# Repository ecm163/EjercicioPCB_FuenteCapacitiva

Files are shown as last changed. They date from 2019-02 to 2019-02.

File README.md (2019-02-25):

# EjercicioPCB_FuenteCapacitiva

Ejercicio Simulación y Diseño del PCB de una Fuente Capacitiva (hecho por ecm163).

La fuente capacitiva es un circuito que transforma una corriente alterna, por ejemplo la de 220  voltios rms de la red, 
en una continua de menor voltaje, en este ejercicio unos 5 voltios aproximadamente. 

En éste ejercicio se hacen dos cosas:

1- Se diseña y simula el circuito en Orcad y Pspice (versión 17.2).

2- Se diseña su correspondiente PCB con Altium Designer.

Una descripción sintética sel ejercicio se en el PDF que se adjunta con el nombre: 

"Ejercicio Simulación y Diseño del PCB de una Fuente Capacitiva".

Dentro de la carpeta: "Fuente capacitiva" tenemos dos carpetas más.

- "EjercicioOrcadPCB". En ésta carpeta se encuentran los archivos correspondientes al proyecto en Orcad (versión 17.2),
  que consta de su esquemático para ser simulado. Si dispone del Orcad puede navegar en ésta carpeta y abrir el proyecto.
  
- "EjercicioAltium". En ésta carpeta se encuentran los archivos correspondientes al proyecto en Altium Designer,
  que consta de su esquemático y el layout o PCB final del diseño.
  Si dispone del Altium Designer puede navegar en ésta carpeta y abrir el proyecto.

Un saludo.

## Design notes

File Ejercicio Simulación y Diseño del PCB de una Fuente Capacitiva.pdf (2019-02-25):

## Ejercicio Simulación y Diseño del PCB de una Fuente

Capacitiva.

## Introducción:

La fuente capacitiva es un circuito que transforma una corriente alterna, por ejemplo la de 220 voltios rms de la red, en una continua de menor voltaje, en este ejercicio unos 5 voltios aproximadamente.

Hay otra forma de realizar esta operación con un transformador. De esta forma se usa el efecto capacitivo de un condensador electrolítico previamente rectificado la señal en alterna por un puente de diodos, además de un diodo zener para fijar una tensión de salida entre otros componentes. Como todo está forma de realizar el propósito tiene sus ventajas e inconvenientes.

La parte de simulación está hecha con la última versión de Orcad (la 17.2) y su correspondiente Pspice. Yo he manejado versiones más antiguas de Orcad con las que no me resultaba difícil sacar la PCB, y dónde la herramienta era el layout o layout plus, en esta versión la herramienta es el PCB editor, que en mi ordenador va muy lento.

Como no controlo tan bien el PCB editor y va excesivamente lento decidí finalmente desarrollar el PCB con Altium, incluso aunque mi versión de Altium Designer va “a trompicones”, es una herramienta con la que tengo más soltura y se trataba de hacer algo de la mejor forma en poco tiempo.

El desarrollo y diseño del ejercicio es mejorable, pero creo que puede ser suficiente para demostrar que tengo cierto manejo en simulación y diseño de PCBs.

Dado que esto no es un tutorial, en la sucesivo trataré de ser lo más sintético posible usando más capturas de pantalla que mucha literatura.
Simulación con Orcad-Pspice.

En primer lugar diseñé el esquemático en la herramienta Capture del Orcad para comprobar que el circuito funciona:

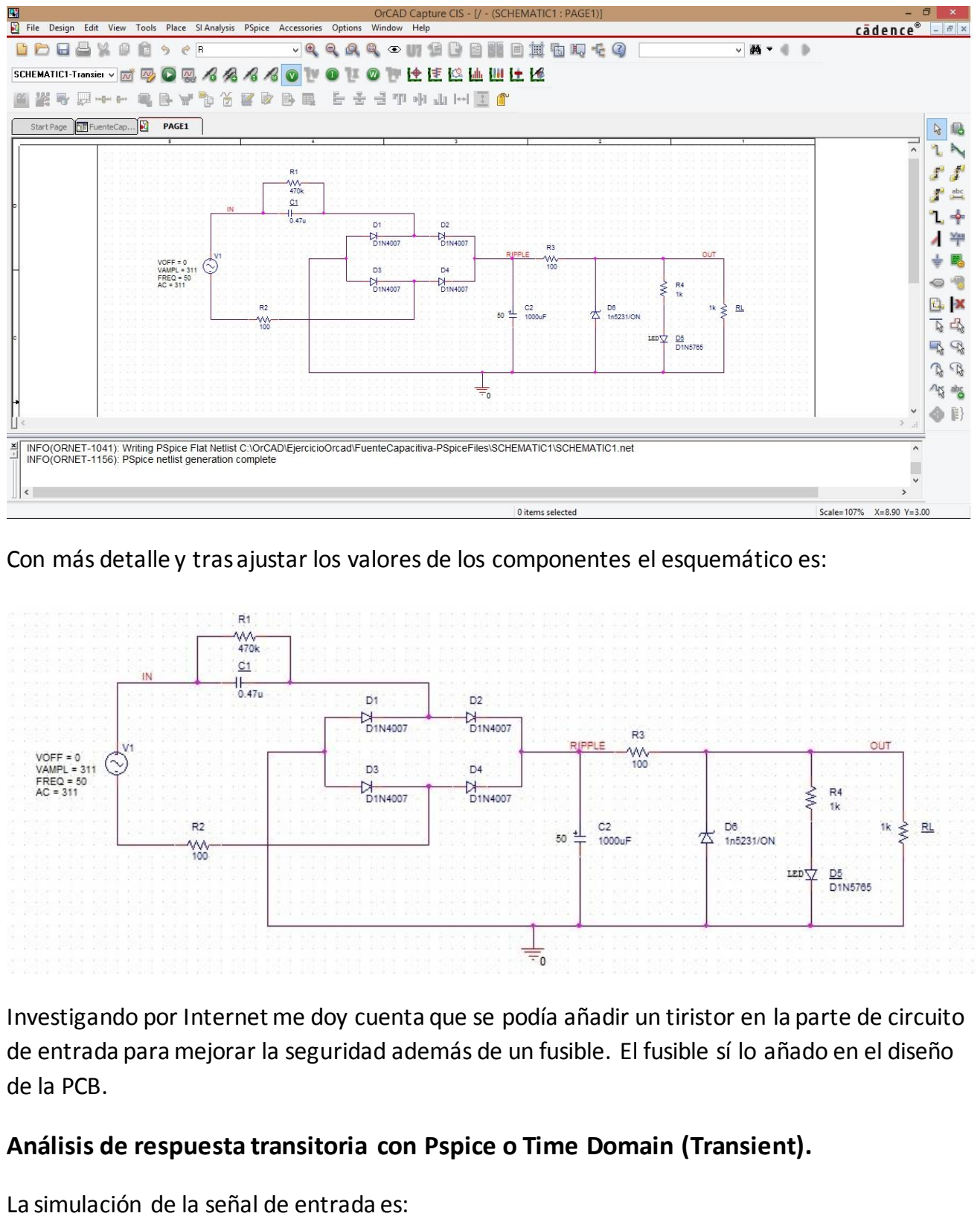
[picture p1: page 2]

Con más detalle y trasajustar los valores de los componentes el esquemático es:

Investigando por Internet me doy cuenta que se podía añadir un tiristor en la parte de circuito de entrada para mejorar la seguridad además de un fusible. El fusible sí lo añado en el diseño de la PCB.

Análisis de respuesta transitoria con Pspice o Time Domain (Transient).

La simulación de la señal de entrada es:

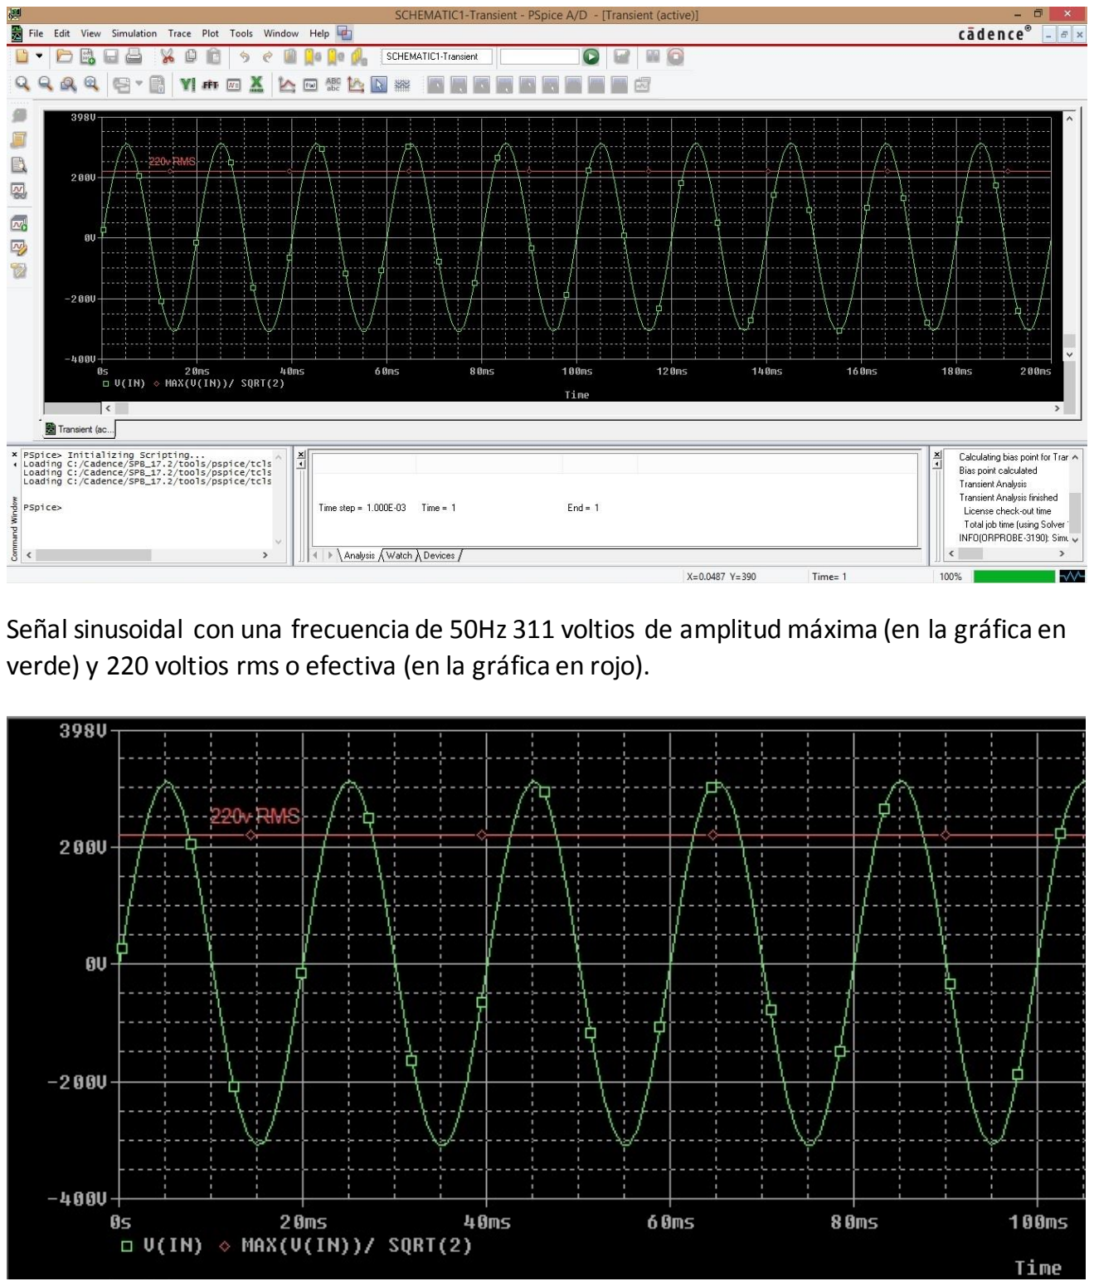
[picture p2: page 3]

Señal sinusoidal con una frecuencia de 50Hz 311 voltios de amplitud máxima (en la gráfica en verde) y 220 voltios rms o efectiva (en la gráfica en rojo).

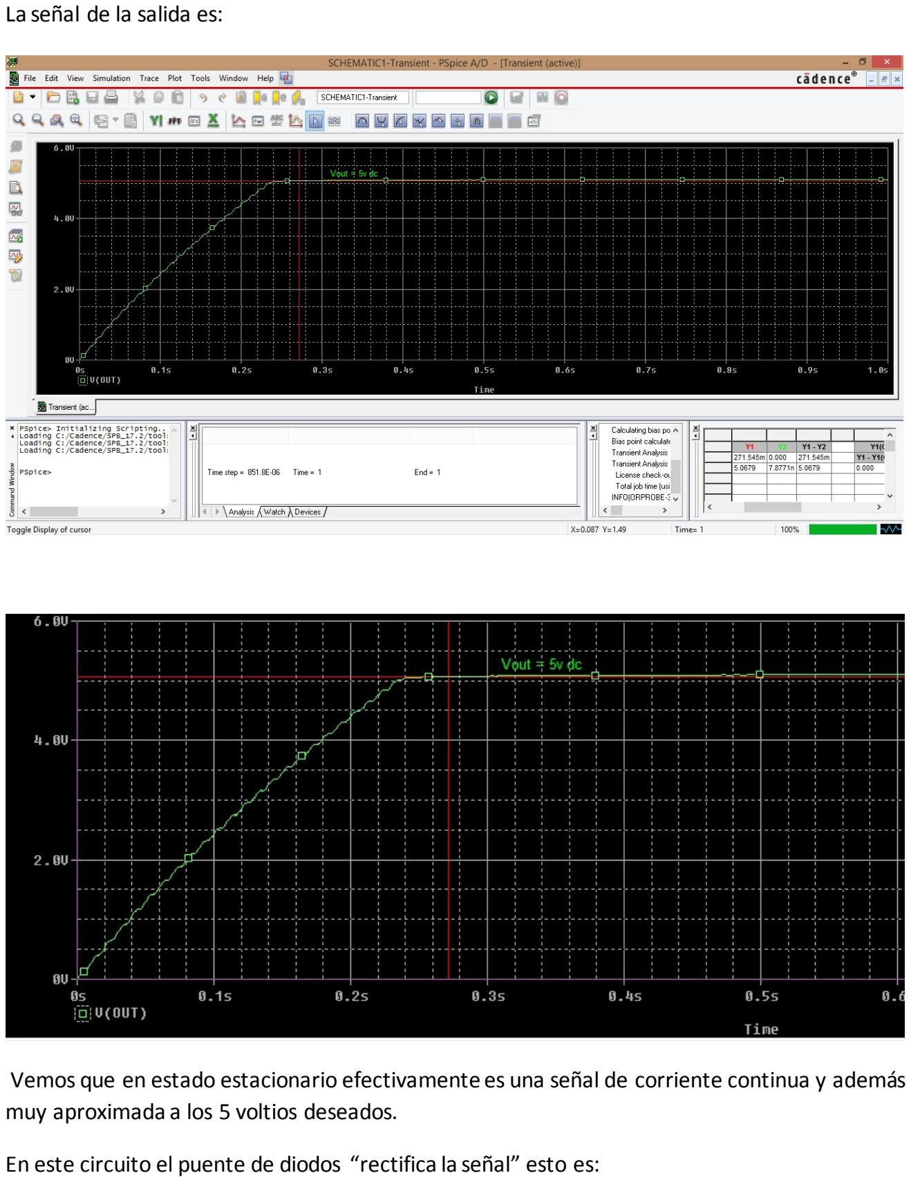
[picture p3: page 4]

La señal de la salida es:

Vemos que en estado estacionario efectivamente es una señal de corriente continua y además muy aproximada a los 5 voltios deseados.

En este circuito el puente de diodos “rectifica la señal” esto es:

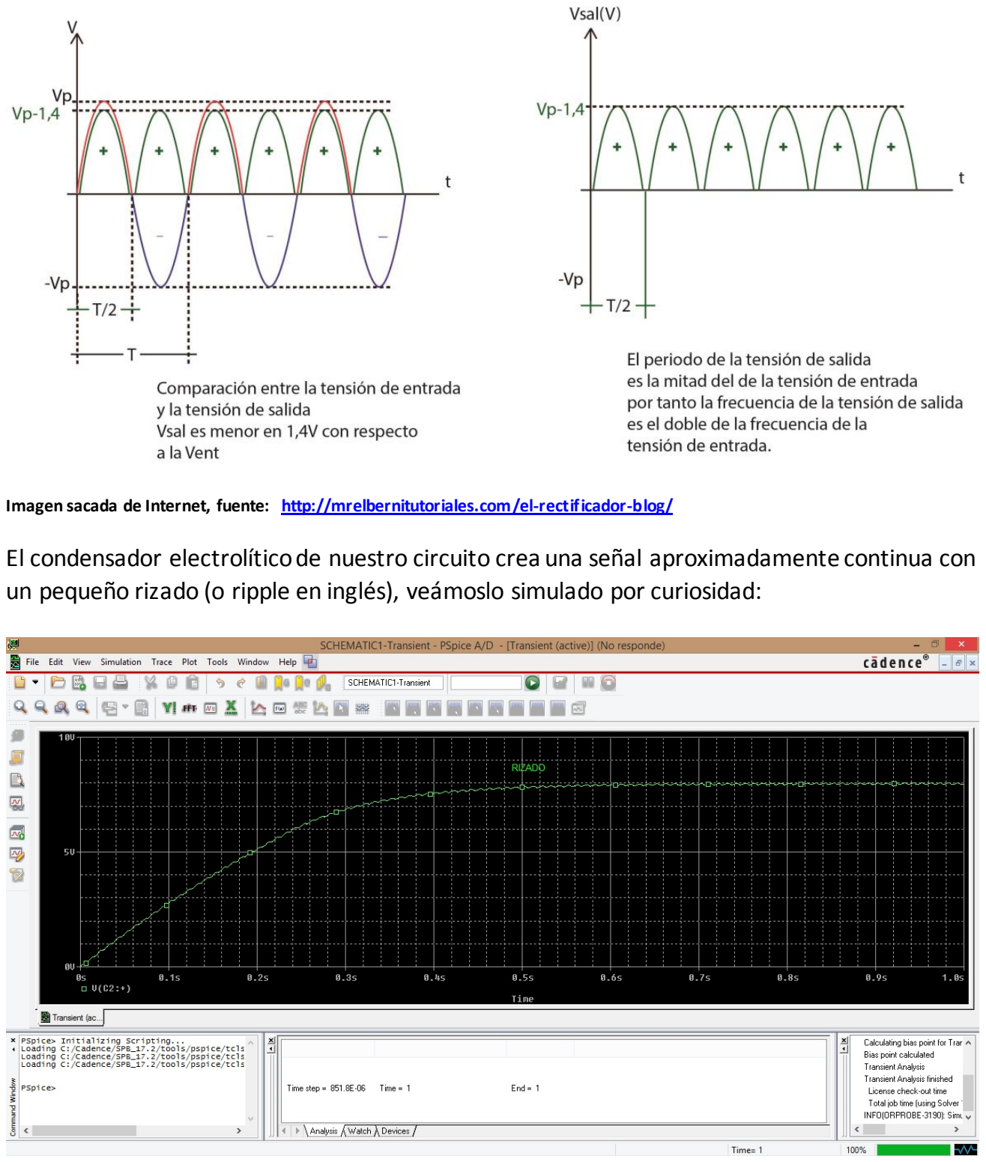
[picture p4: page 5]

Imagen sacada de Internet, fuente: http://mrelbernitutoriales.com/el-rectificador-blog/

El condensador electrolítico de nuestro circuito crea una señal aproximadamente continua con un pequeño rizado (o ripple en inglés), veámoslo simulado por curiosidad:

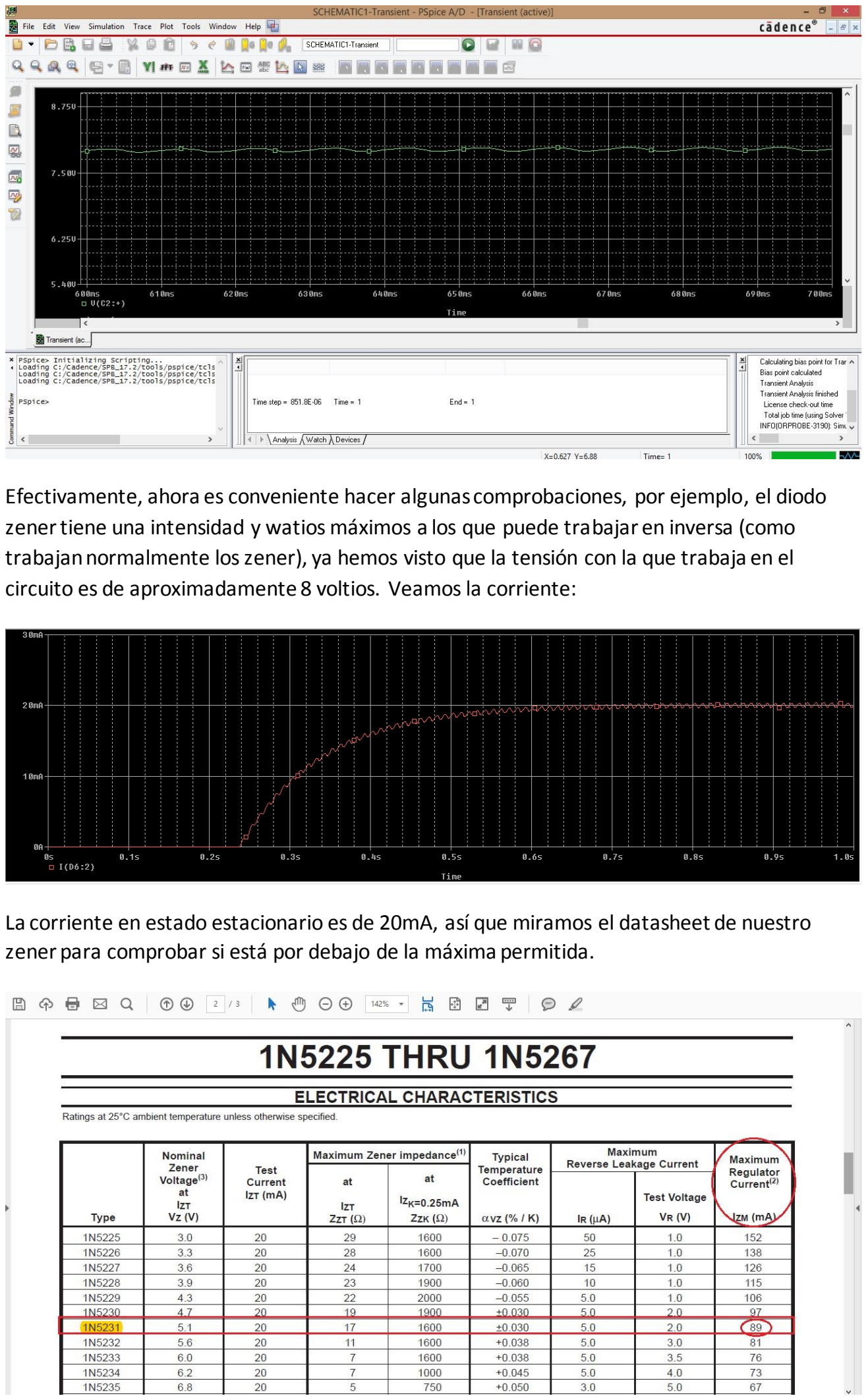
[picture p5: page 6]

Efectivamente, ahora es conveniente hacer algunas comprobaciones, por ejemplo, el diodo zener tiene una intensidad y watios máximos a los que puede trabajar en inversa (como trabajan normalmente los zener), ya hemos visto que la tensión con la que trabaja en el circuito es de aproximadamente 8 voltios. Veamosla corriente:

La corriente en estado estacionario es de 20mA, así que miramos el datasheet de nuestro zener para comprobar si está por debajo de la máxima permitida.

Tenemos 20mA, por debajo de los 89mA máximos permitidos. Vamos bien.

Además los watios que soporta el zenersería de 0,5 o 1 (ya no recuerdo), pongamos el peor caso, 0,5w. Como sabemos la corriente que pasa por él y la caída de tensión (20mA y 8V respectivamente)sería aproximadamente de:

W = I x V = 0,16w

Bastante por debajo de 0,5w.

No está mal hacer comprobaciones de este tipo. Además como la tensión suministrada no es fija siempre a 220v (hay picos de tensión que sobrepasan los 311v de amplitud) no está de más hacer un análisis AC sweep entre las amplitudes de la señal correspondientes a por ejemplo 200 y 240 voltios rms o eficaces (esto es, entre 140v y 170v de amplitud máxima aproximadamente). Pero es mejor no alargar mucho más esto.
Diseño del PCB con el Altium Designer.

El esquemático en el Altium -en el que añado un fusible, sustituyo la fuente ac por un terminal de empalme de cables para PCBs a la entrada y un conector de salida- sería:

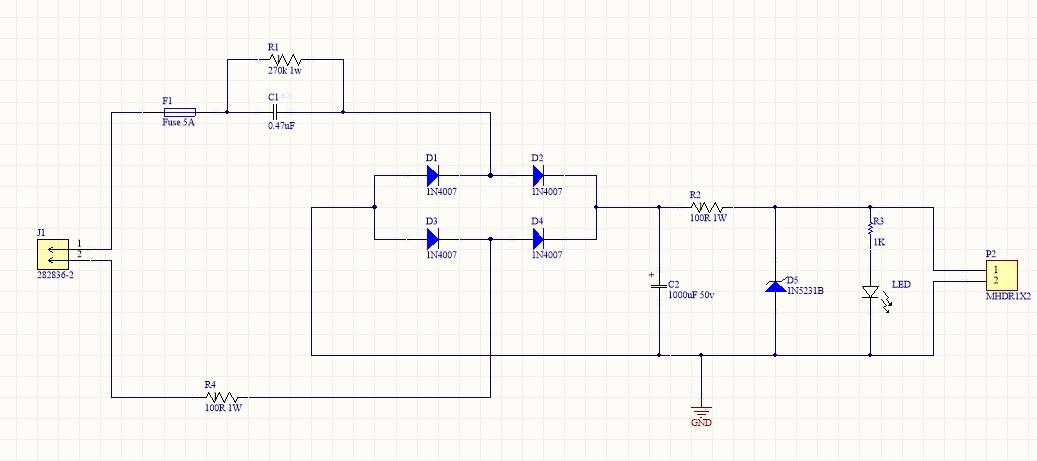
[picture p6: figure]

En el proceso de diseño del esquemático me aseguré de que cada componente tuviera su footprint real, el del componente que seleccioné (en páginas como digikey, RS-online, Farnell …etc).

¿Cómo hice esto?, bueno, en algún caso tiré de datasheet e hice el diseño correspondiente con el Altium (clic botón derecho en el proyecto, desplegable, add new to Project/PCB Library).

Otros estaban en las librerías que he recopilado con el tiempo de Altium, y por último algunos suministradores de componentes -como digkey- te dan la posibilidad de descargarte y trasla ejecución de scripts obtener el esquemático del componente con su footprint (con una herramienta llamada ultra-librarian).

También está la opción para descargar modelos de una página llamada SanapEda, pero mientras que en el Orcad me iba muy bien, en mi versión de Altium no …

Componente: | Unidades | N o Serie Fabricante | Breve descripción
J1 | 1 | 282836-2 | Bloque de terminales fijos
F1 | 1 | 0876005.MRET1P | Fusible 250v 5A
C1 | 1 | MKT1822447405 | Condensador poliéster de 0,47uF 400v
C2 | 1 | UVY1H102MHD | Condensador electrolítico 1000uF y 50v
R1 | 1 | PR01000104703JR500 | Resistencia 270k y 1W
R2,R4 | 2 | FMP100JR-52-100R | Resistencias 100 y 1W
R3 | 1 | CF14JT1K00 | Resistencia 1k y 0,25W (el tipo habitual)
D1,D2,D3 y D4 | 1 | 1N4007 | Diodo de propósito general de 1ª 1Kv
D5 | 1 | 1N5231BTR | Diodo zener 5,1v y 0,5w
LED | 1 | HLMP-1301 | LED orificio pasante (los más habituales)
P2 | 1 | HDR1X2-M254-72 | Conectores PCB macho

Si completáramosla anterior tabla con más información como el vendedor, marca del fabricante … y añadiría el precio, tendríamos lo que se llama la “bill of material” o conocido con el acrónimo de BOM, dejo la anterior tabla para atestiguar que he trabajado la cuestión de la elección de componentes. No ha sido al azar.

Una vez hecho el esquemático y la selección de componentes y sus footprints diseñé el PCB:

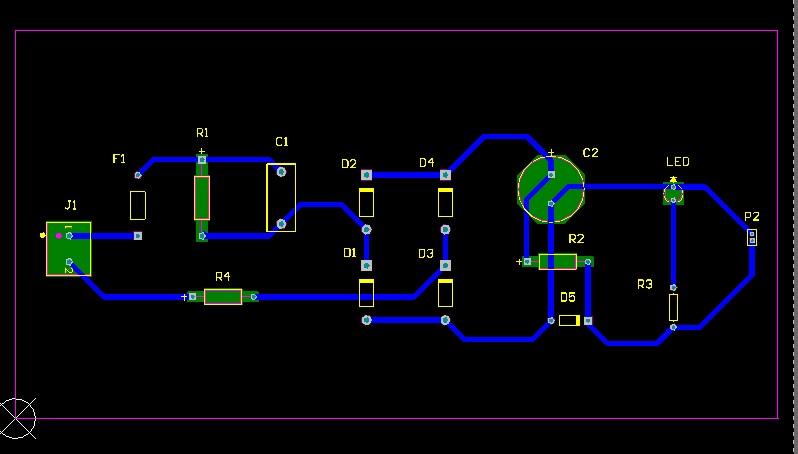
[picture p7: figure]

El ruteado lo hice manual, las pistas son de 40 mils (o milipulgadas) que corresponde aproximadamente a un milímetro en sistema métrico, en este caso creo que es un ancho de pista óptimo. El borde de la placa (en morado) aquí lo he puesto como me ha parecido, pero en caso de que el diseño fuera para fabricación lo óptimo es ajustar sus dimensiones a los estándares del fabricante.

A continuación le incorporamos un plano a masa, más concretamente a tierra, mejora la respuesta al ruido y evita corrientes parásitas.

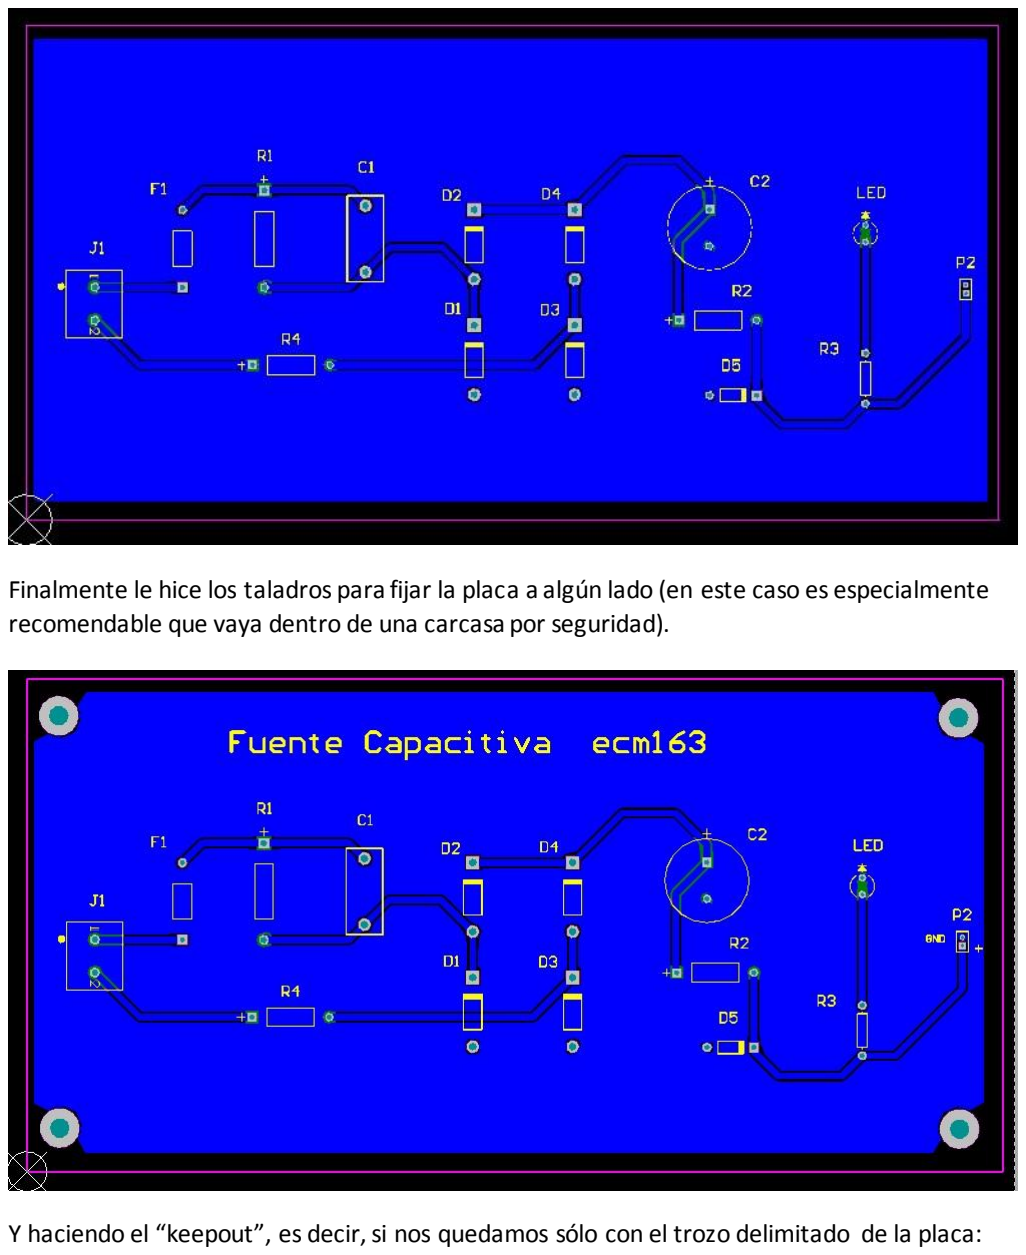
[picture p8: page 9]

Finalmente le hice los taladros para fijar la placa a algún lado (en este caso es especialmente recomendable que vaya dentro de una carcasa por seguridad).

Y haciendo el “keepout”, es decir, si nos quedamos sólo con el trozo delimitado de la placa:

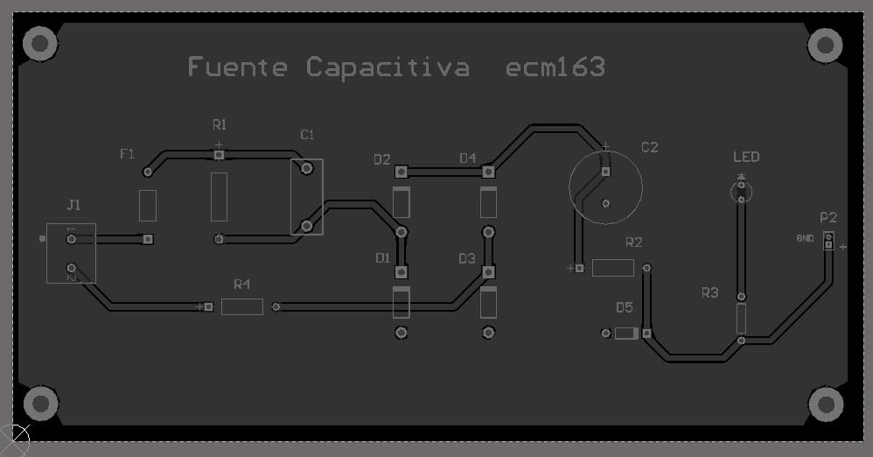
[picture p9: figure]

Para mandar a fabricar el PCB tendríamos que sacar los archivos Gerber, para ello seleccionamos la pestaña File, la opción Frabrication Outputs.

Ahí establecemos diversos parámetros cómo el tipo de unidades (sistema métrico o imperial), el formato de los archivos Gerber (usualmente RS274X), las capas etc.

Las capas o layers que normalmente se seleccionan (o al menos yo lo hago así) son las siguientes:

- GTL para la capa superior (TOP)
- GBL para la capa inferior (BOT)
- GTS para la capa de antisolder superior (TOP MASK)
- GBS para la capa de antisolder inferior (BOT MASK)
- GTO para la capa de Leyenda de Componentes superior (TOP SILK)
- GBO para la capa de Leyenda de Componentes inferior (BOT SILK)
- GM1 para la capa de Borde o Corte externo del circuito (CUT)

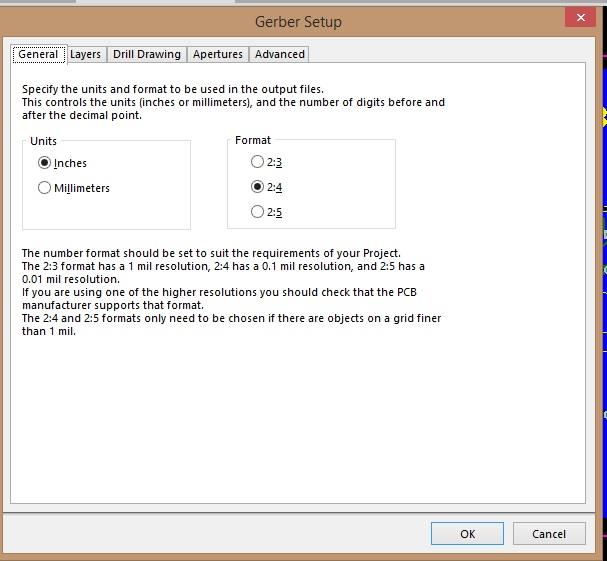
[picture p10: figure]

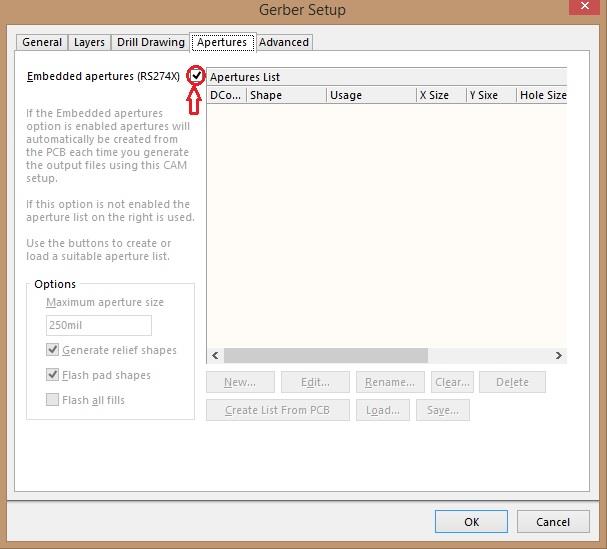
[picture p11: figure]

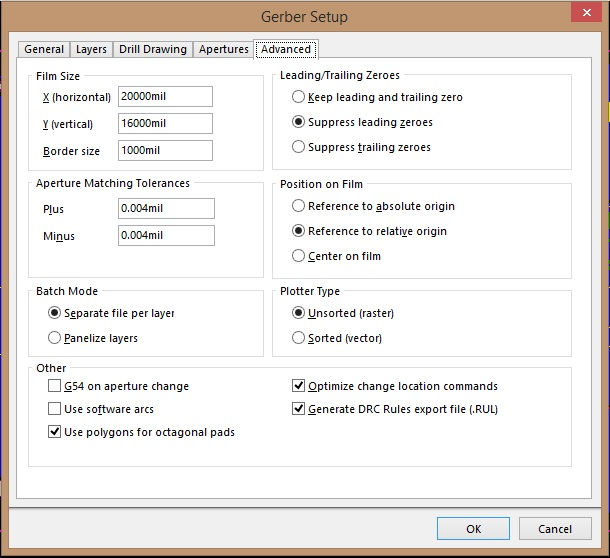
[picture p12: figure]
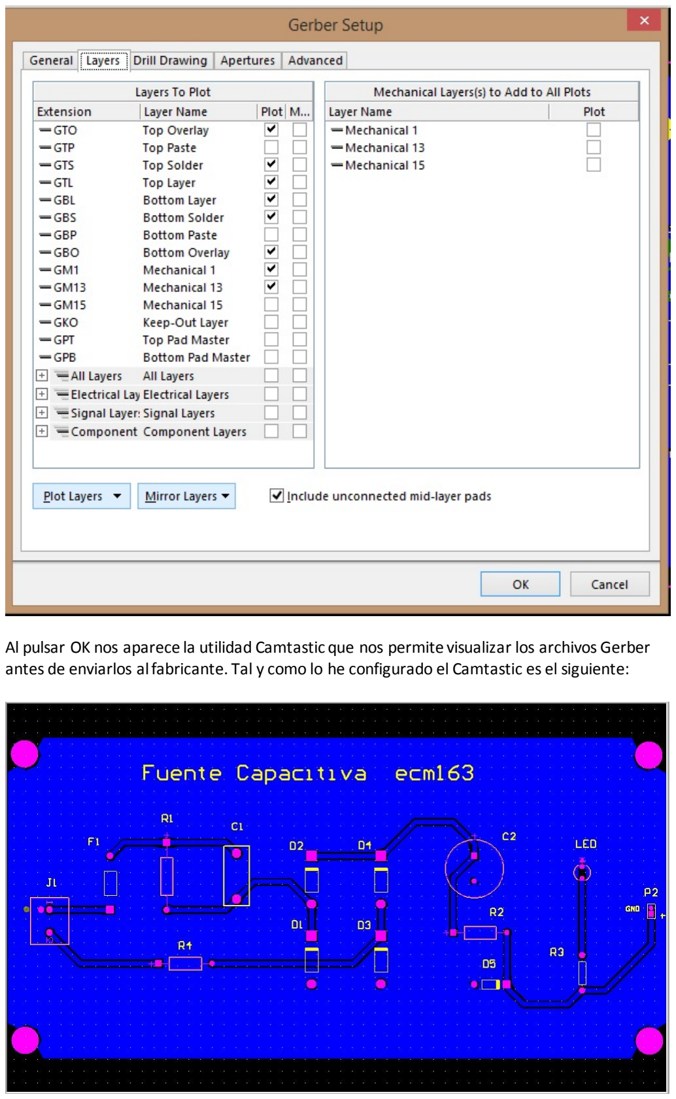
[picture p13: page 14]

Al pulsar OK nos aparece la utilidad Camtastic que nos permite visualizar los archivos Gerber antes de enviarlos al fabricante. Tal y como lo he configurado el Camtastic es el siguiente:

Los archivos Gerber se han generado automáticamente en una carpeta dentro del proyecto llamada “Project Output”.

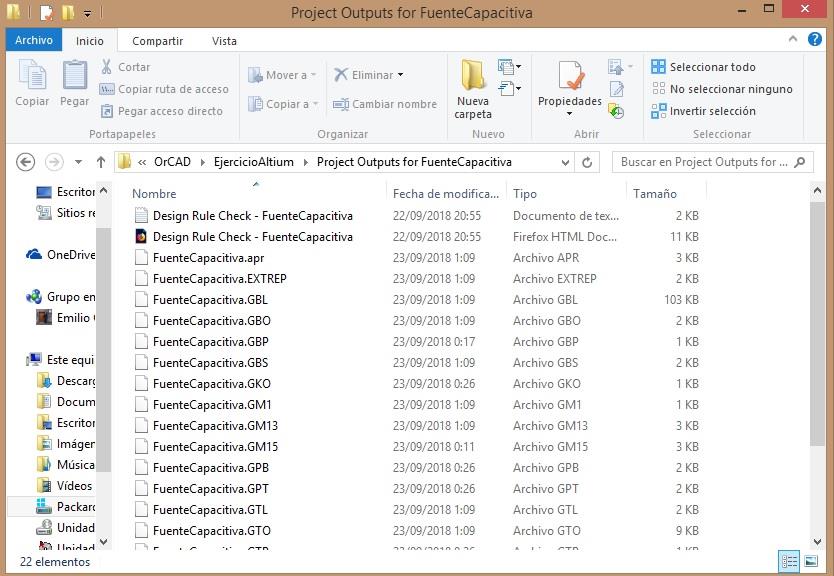
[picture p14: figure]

Según las capas o layers que seleccionemos y si lo vemos desde arriba o abajo (seleccionando los casilleros top o mirror), tendremos distintas perspectivas desde las que ver nuestro PCB y las distintas capas que lo forman, por ejemplo.

Capa “silkscreen u overlay” (en verde en la imagen) y “top solder” (en morado en la imagen) todo visto desde arriba (en morado también están los taladros en las esquinas de la placa):

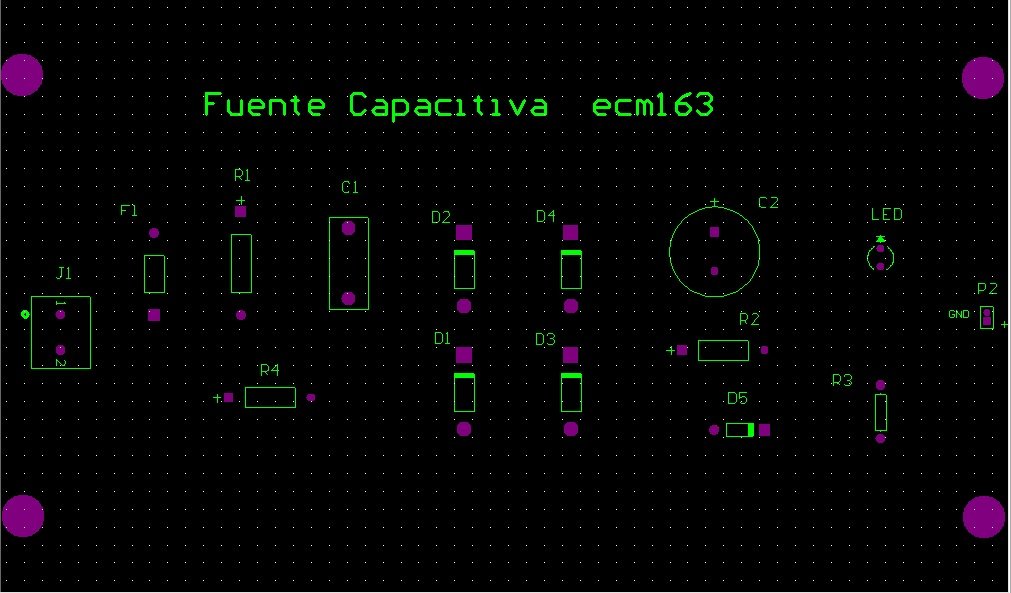
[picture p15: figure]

La capa “silkscreen” u “overlay” con los “silk”, es una de las capas superiores que incluye serigrafiado y demarcaciones de componentes, en los PCB los “silk” tienen color blanco con el tradicional fondo verde u de otro color de la máscara antisoldante o “solder mask”.

La capa “top solder” incluyen los pads para soldauras.

A continuación muestro una vista desde arriba del bottom layer y las soldaduras, es decir una vista desde arriba de la parte inferior del PCB dónde se encuentran las pistas o tracks de este circuito así como el plano de masa y las soldaduras.

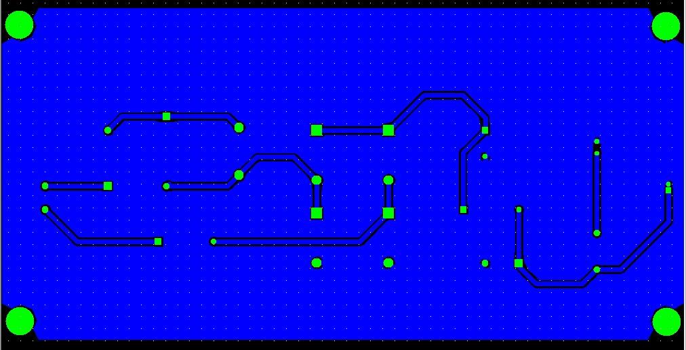
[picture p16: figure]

En el siguiente sería lo mismo que en la anterior imagen pero vista desde abajo, es decir, como si hubiéramos dado la vuelta al PCB (por eso a este tipo de vistas en Camtastic se le llaman mirror o espejo):

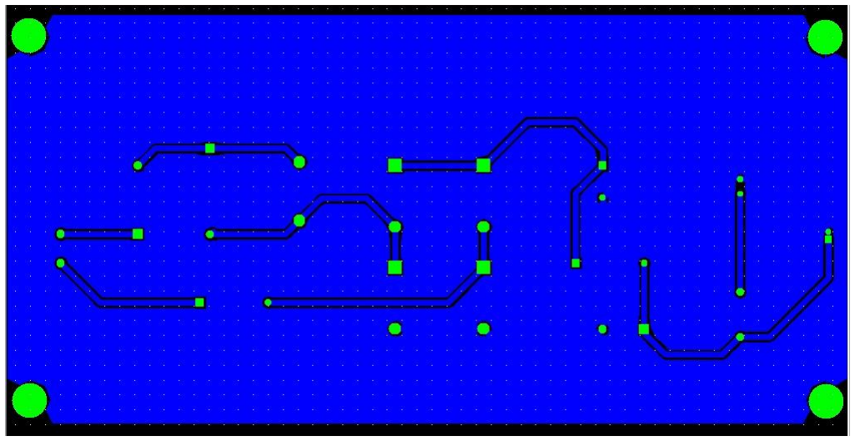
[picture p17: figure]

Hay otra manera de previsualizar el PCB, además esta otra forma nos permite imprimir por si queremos hacer el PCB de manera casera en lugar de pedírselo a un fabricante de PCBs (con el método del planchado por ejemplo). Sería con la opción File/Fabricatio outputs/Final. Muestro dos vistas a modo de ejemplos:

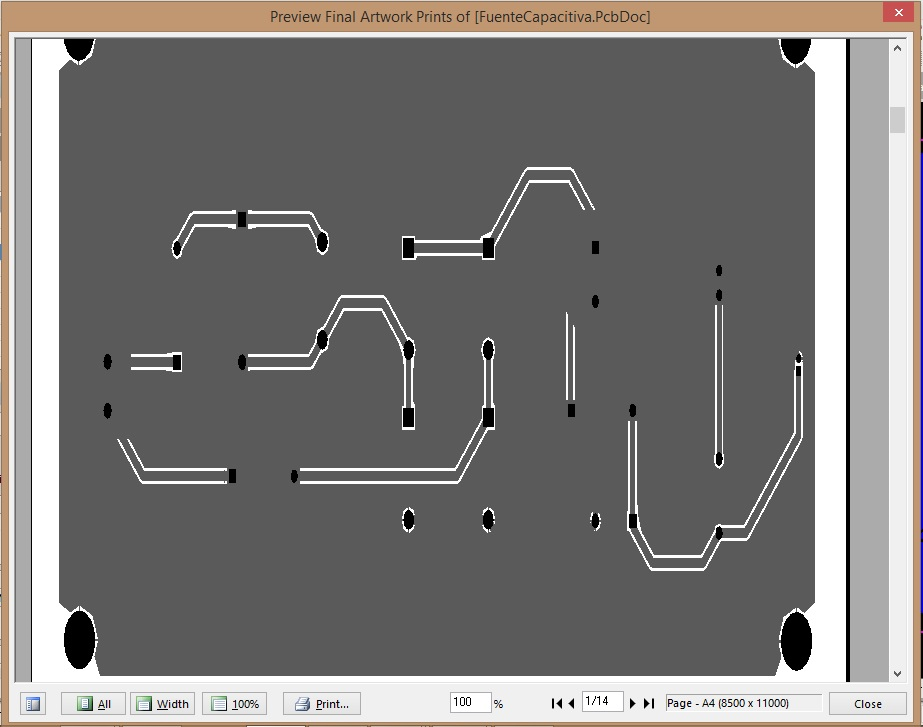
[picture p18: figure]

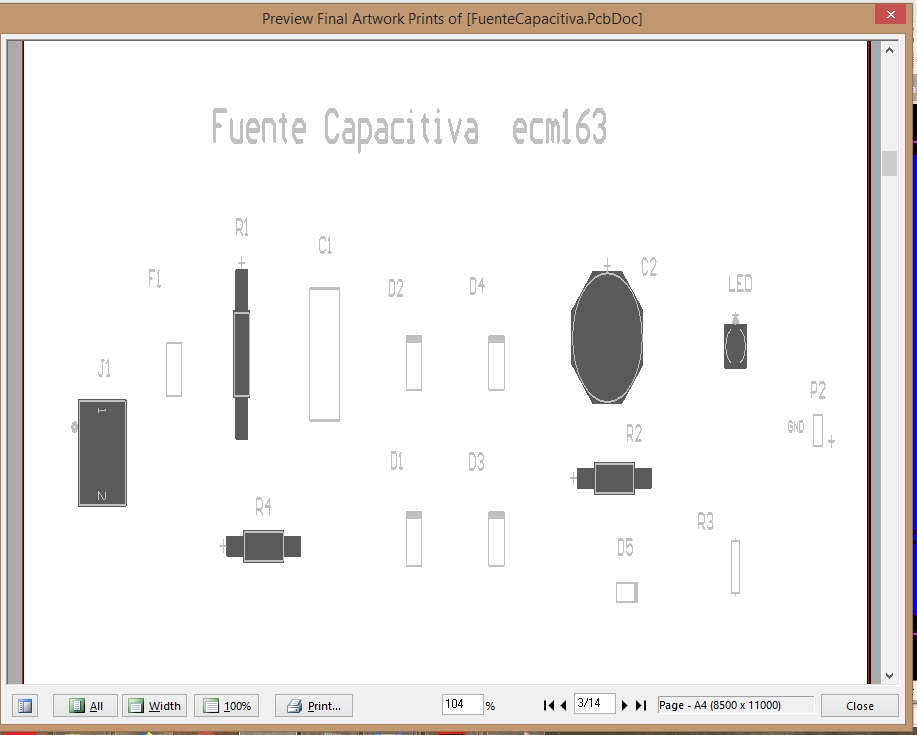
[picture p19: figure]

Bueno, con lo documentado hasta ahora espero haber mostrado el proceso de simulación y diseño de la PCB de este ejercicio, así como mostrar que tengo conocimientos de estas cosas.

Gracias por la atención.

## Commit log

2019-02-25 Ejercicio PCB Fuente Capacitiva
    [FUENTECAPACITIVAPCB.DSN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]
2019-02-25 # EjercicioPCB_FuenteCapacitiva
    Ejercicio Simulación y Diseño del PCB de una Fuente Capacitiva (hecho por ecm163.
    La fuente capacitiva es un circuito que transforma una corriente alterna, por ejemplo la de 220 voltios rms de la red,
    en una continua de menor voltaje, en este ejercicio unos 5 voltios aproximadamente.
    En éste ejercicio se hacn dos cosas:
    1- Se diseña y simula el circuito en Orcad y Pspice (versión 17.2).
    2- Se diseña su correspondiente PCB con Altium Designer.
    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
2019-02-25 # EjercicioPCB_FuenteCapacitiva
    Ejercicio Simulación y Diseño del PCB de una Fuente Capacitiva (hecho por ecm163).
    En éste ejercicio se hacen dos cosas:
    Una descripción sintética sel ejercicio se en el PDF que se adjunta con el nombre:
    "Ejercicio Simulación y Diseño del PCB de una Fuente Capacitiva".
    Dentro de la carpeta: "Fuente capaci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
